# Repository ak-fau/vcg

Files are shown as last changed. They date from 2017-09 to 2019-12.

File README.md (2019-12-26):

# Versatile Clock Generator (VCG)

The VCG module is a stable and precise frequency source designed to be used
in experiments with time keeping (GPSDO), clock synchronization (PTPv2, IEEE-1588)
and Software Defined Radio (SDR).  Base frequency tuning, PLL configuration
and system monitoring (temperature and power consumption) are implemented
with I2C-bus connected devices.

The hardware is designed with free/open-source KiCAD EDA Software Suite.

_**Disclaimer**
The design and ideas are not very original ones, there are many similar devices
available in real products or on the Internet. The sole purpose of this
project is to build a convenient and universal module for the author's own
education and use and to release it explicitly as a Free Hardware Design._

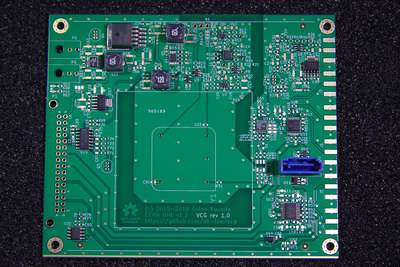
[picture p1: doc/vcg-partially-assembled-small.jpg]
Partially assembled VCG board


## Structure

The VCG board is build around oven controlled crystal oscillator (OCXO).

10 MHz output of the oscillator is buffered on the board with low
skew/low jitter clock driver IC and routed to receivers.
A programmable PLL synthesizer/multiplier/dividers synchronized to
the base frequency is provided on the board to generate output
frequencies up to 300 MHz.

Board temperature and OCXO power consumption are monitored with a
system controller device connected to an I2C bus. This I2C bus is also
used to access PLL control registers, DAC for oscillator tune voltage
and EEPROM (or FRAM) for calibration parameters and log data.  All
the control signals and output frequency are available on
a control board connector.  Future plans include design of an MCU and/or
FPGA based control boards tailored for different applications.
Base output frequency and programmable PLL outputs are routed
to the SMA connector (single ended LVCMOS signals) and SATA-type
connector (LVDS signals) for external use.

The module is powered from external stabilized +5V power supply,
all internal circuits run at +3.3V power obtained with two on-board
LDO regulators.

### Crystal Oscillator

Abracon AOCJY3-10.000MHz OCXO (0..50 oC, +/-5ppb) is used as a base
frequency source on the board.

For experiments with other (less accurate/less stable) crystals and to
test system monitoring circuits a separate small module is developed.
The module may be plugged into the main VCG board in place of AOCJY3
oscillator and provides 10 MHz output (10ppb..50ppm) and +3.3V power
load (up to five 10 Ohm resistors connected in parallel).  Design
files for the module are available under osc/ directory.

### PLL

Texas Instruments CDCE706

### Clock buffers

 - LV-CMOS
   Texas Instruments CDCLVC1104/06

 - LVDS
   Texas Instruments SN65LVDS1

### Oscillator tune voltage DAC

Linear Technology LTC2607-1

### System monitoring

Texas Instruments TMP512

### Calibration parameters and data log F-RAM

Cypress Semiconductors FM24CL64B

## References

### Power connector

### Control module connector

### Output connectors

### Components documentation

## License

The VCG is a Free Hardware project, it is released under
dual licenses:

 - CERN Open Hardware License (OHL) v1.2
 - Community Research and Academic Programming License (CRAPL)

All design documents (including textual description, diagrams,
schematic, PCB layout and manufacturing files) are released under CERN
OHL v1.2.  The design is done with KiCAD EDA Software Suite which is
available under GNU GPL v2.

The author will appreciate to be informed about any use of the project
documents under Section 4.2 of the CERN OHL v1.2, but does not require
so.

In addition to the CERN OHL v1.2 all the project materials are covered
by Community Research and Academic Programming License (CRAPL).

Associated software, firmware, bitware (programmable logic
configuration) required for the VCG use will be licensed separately
under free/open-source software license(s) decided upon at a respective
release time.

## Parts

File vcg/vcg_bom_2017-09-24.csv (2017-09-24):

Designator | Manufacturer Part Number | Quantity
C66,C95,C92,C91,C90,C89,C86,C85,C82,C81,C80,C79,C76,C75,C70,C69,C45,C44,C41,C40,C39,C37,C36,C35,C34,C33,C31,C30,C28,C26,C25,C24,C23,C22,C18,C14,C7,C4,C3 | C0603C104K8RACTU | 39
L13,L14,L12 | 7447779112 | 3
U21,U17 | TPS73633DCQR | 2
R79,R38,R35,R34,R8,R7,R6,R5,R4 | ERJ-3GEY0R00V | 9
C96,C93,C84,C83,C78,C77,C72,C71,C68,C67,C65,C64,C63,C38,C17 | C1210C106K8RACTU | 15
C94,C74,C73,C62,C61,C58,C57,C56,C55,C54,C52,C51,C50,C49,C20,C11 | C0603C103K8RACTU | 16
J2 | 0678005003 | 1
U20 | FM24CL64B-G | 1
U19 | TMP512AID | 1
U18 | TPS78633KTT | 1
U15,U14,U11,U10 | SN65LVDS1DBV | 4
U13 | CDCE706PW | 1
U12 | CDCLVC1106PW | 1
U9 | LTC6957IMS-4#PBF | 1
U8 | LT6210CS6#PBF | 1
U7,U6,U4,U3 | LTC2050CS5#PBF | 4
U5 | LTC2607CDE-1#PBF | 1
U2 | ADR280ARTZ | 1
U1 | SN74LVC2G66DCTR | 1
T1 | TC1-1TX+ | 1
R78,R75,R51,R50,R44,R25,R24,R18,R3 | ERJ-3EKF1002V | 9
R77,R76,R11,R10 | ERJ-3EKF4752V | 4
R74,R73,R72,R71,R42,R41,R26 | ERJ-3EKF49R9V | 7
R70,R69,R63,R62,R61,R57,R56,R55,R48 | ERJ-3EKF22R0V | 9
R68,R67,R49,R22,R19,R2,R1 | ERJ-3EKF1001V | 7
R66 | ERJ-8CWFR025V | 1
R65,R64,R37 | ERJ-3EKF2490V | 3
R60,R59,R58,R54,R53,R52,R17 | ERJ-3EKF10R0V | 7
R47 | ERJ-3EKF15R0V | 1
R45 | ERJ-3EKF1301V | 1
R43 | ERJ-3EKF1540V | 1
R40,R36 | ERJ-3EKF2001V | 2
R33,R32,R30 | ERJ-3EKF1000V | 3
R31 | ERJ-3EKF75R0V | 1
R29 | ERJ-3EKF4751V | 1
R28,R21,R13 | ERJ-3EKF2002V | 3
R27 | ERJ-3EKF1302V | 1
R20 | HVCB0603FDD20M0 | 1
R16 | ERJ-3EKF2102V | 1
R15,R12,R9 | ERJ-3EKF2802V | 3
R14 | ERJ-3EKF8252V | 1
L11,L10,L9,L8,L7,L6,L2,L1 | LQM18PN4R7MFRL | 8
L5,L3 | LQW21HN2R2J00L | 2
L4 | LQW18ANR13G00D | 1
DS2,DS1 | LTST-C194KSKT | 2
C88,C87,C32,C27 | ECH-U1H101GX5 | 4
C60,C59,C53,C48,C47,C46,C19,C15,C12,C9,C8,C5 | C0805C105K4RACTU | 12
C43 | C0603C332G3GEC7867 | 1
C42 | C1206C225J3RACTU | 1
C29 | ECH-U1H221GX5 | 1
C21,C16,C13,C10,C6 | C0603C102K3RACTU | 5
U16 | LTC4415EMSE#PBF | 1

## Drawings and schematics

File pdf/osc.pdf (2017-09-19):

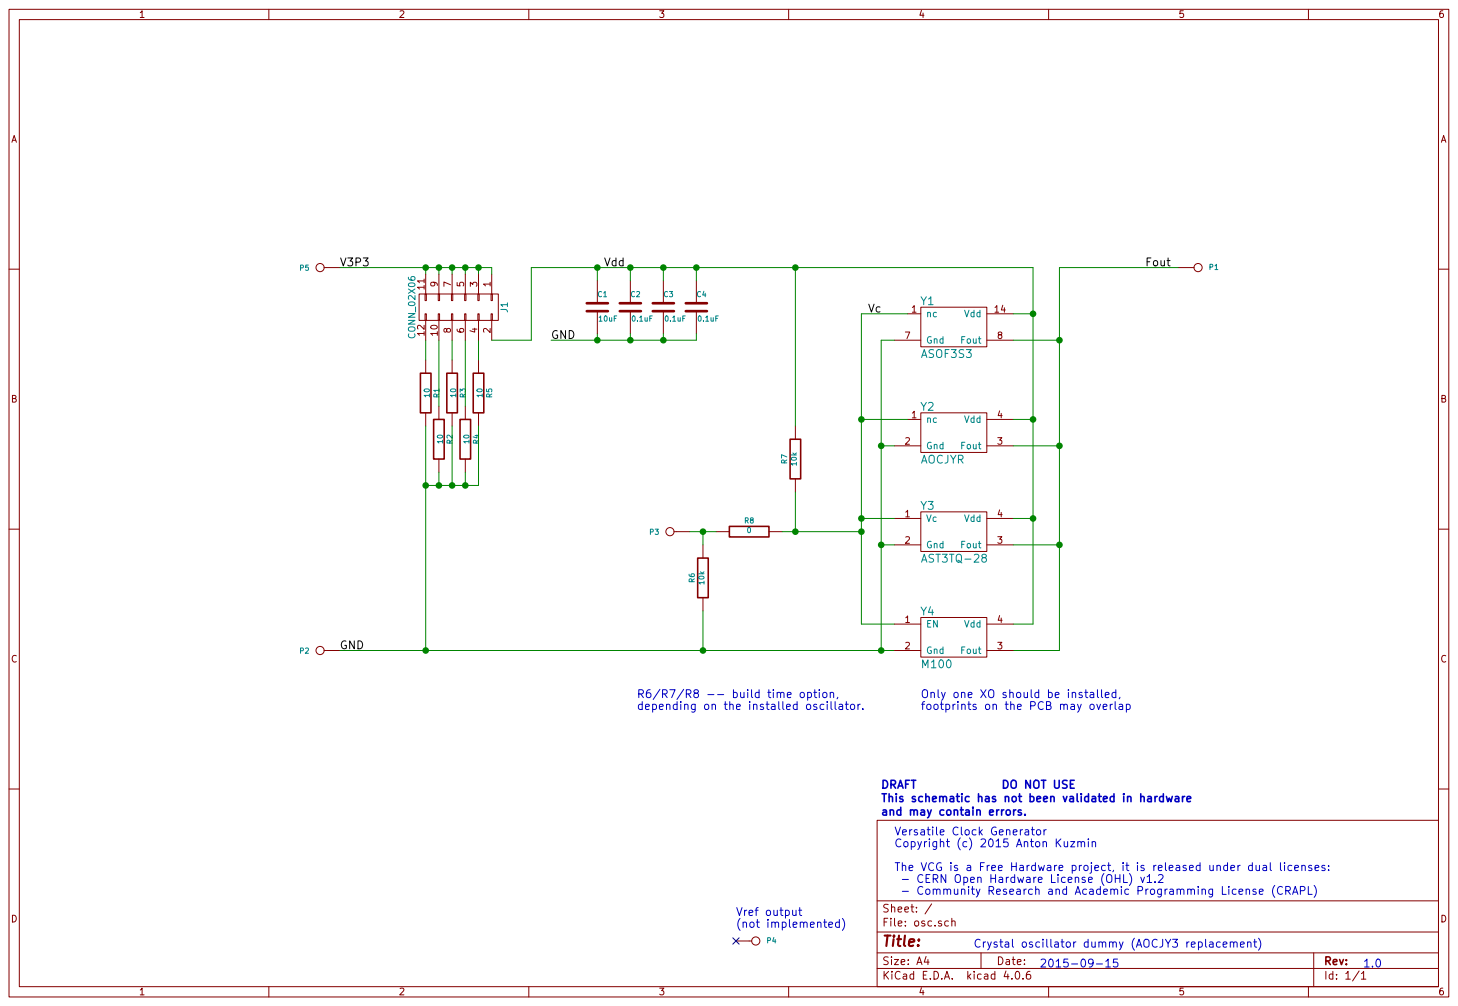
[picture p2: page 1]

Only one XO should be installed,
footprints on the PCB may overlap

This schematic has not been validated in hardware

Versatile Clock Generator
Copyright (c) 2015 Anton Kuzmin
The VCG is a Free Hardware project, it is released under dual licenses:
- CERN Open Hardware License (OHL) v1.2
- Community Research and Academic Programming License (CRAPL)
Id: 1/1 Title: File: osc.sch Sheet: /

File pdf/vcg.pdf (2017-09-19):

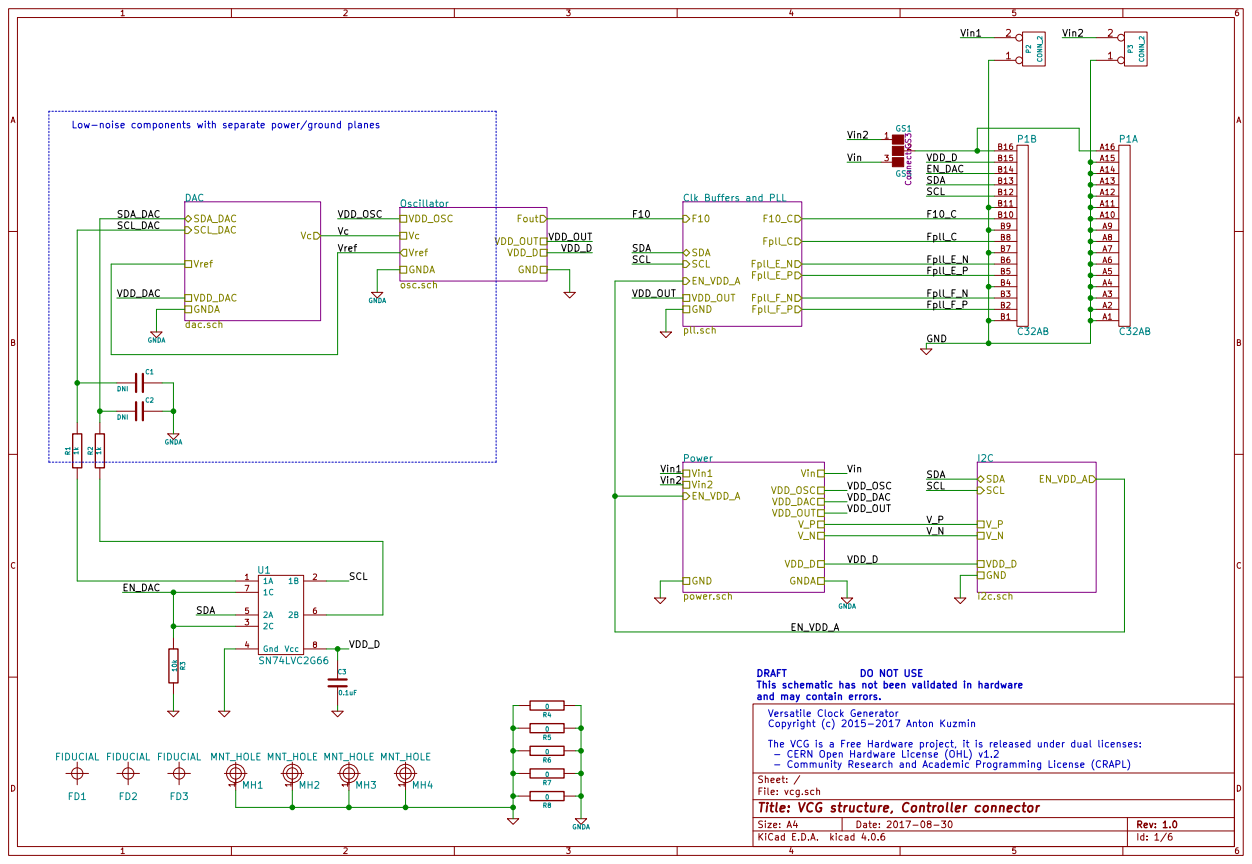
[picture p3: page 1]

Low-noise components with separate power/ground planes

VDD_D
EN_DAC

Clk Buffers and PLL
pll.sch F10 SDA
VDD_OUT Power power.sch
GND

F10 VDD_DAC

Fpll_E_P

Fpll_F_P

This schematic has not been validated in hardware
and may contain errors.
File: vcg.sch Sheet: / Versatile Clock Generator
Copyright (c) 2015-2017 Anton Kuzmin
The VCG is a Free Hardware project, it is released under dual licenses:
- CERN Open Hardware License (OHL) v1.2
- Community Research and Academic Programming License (CRAPL)

Id: 1/6 Title: VCG structure, Controller connector

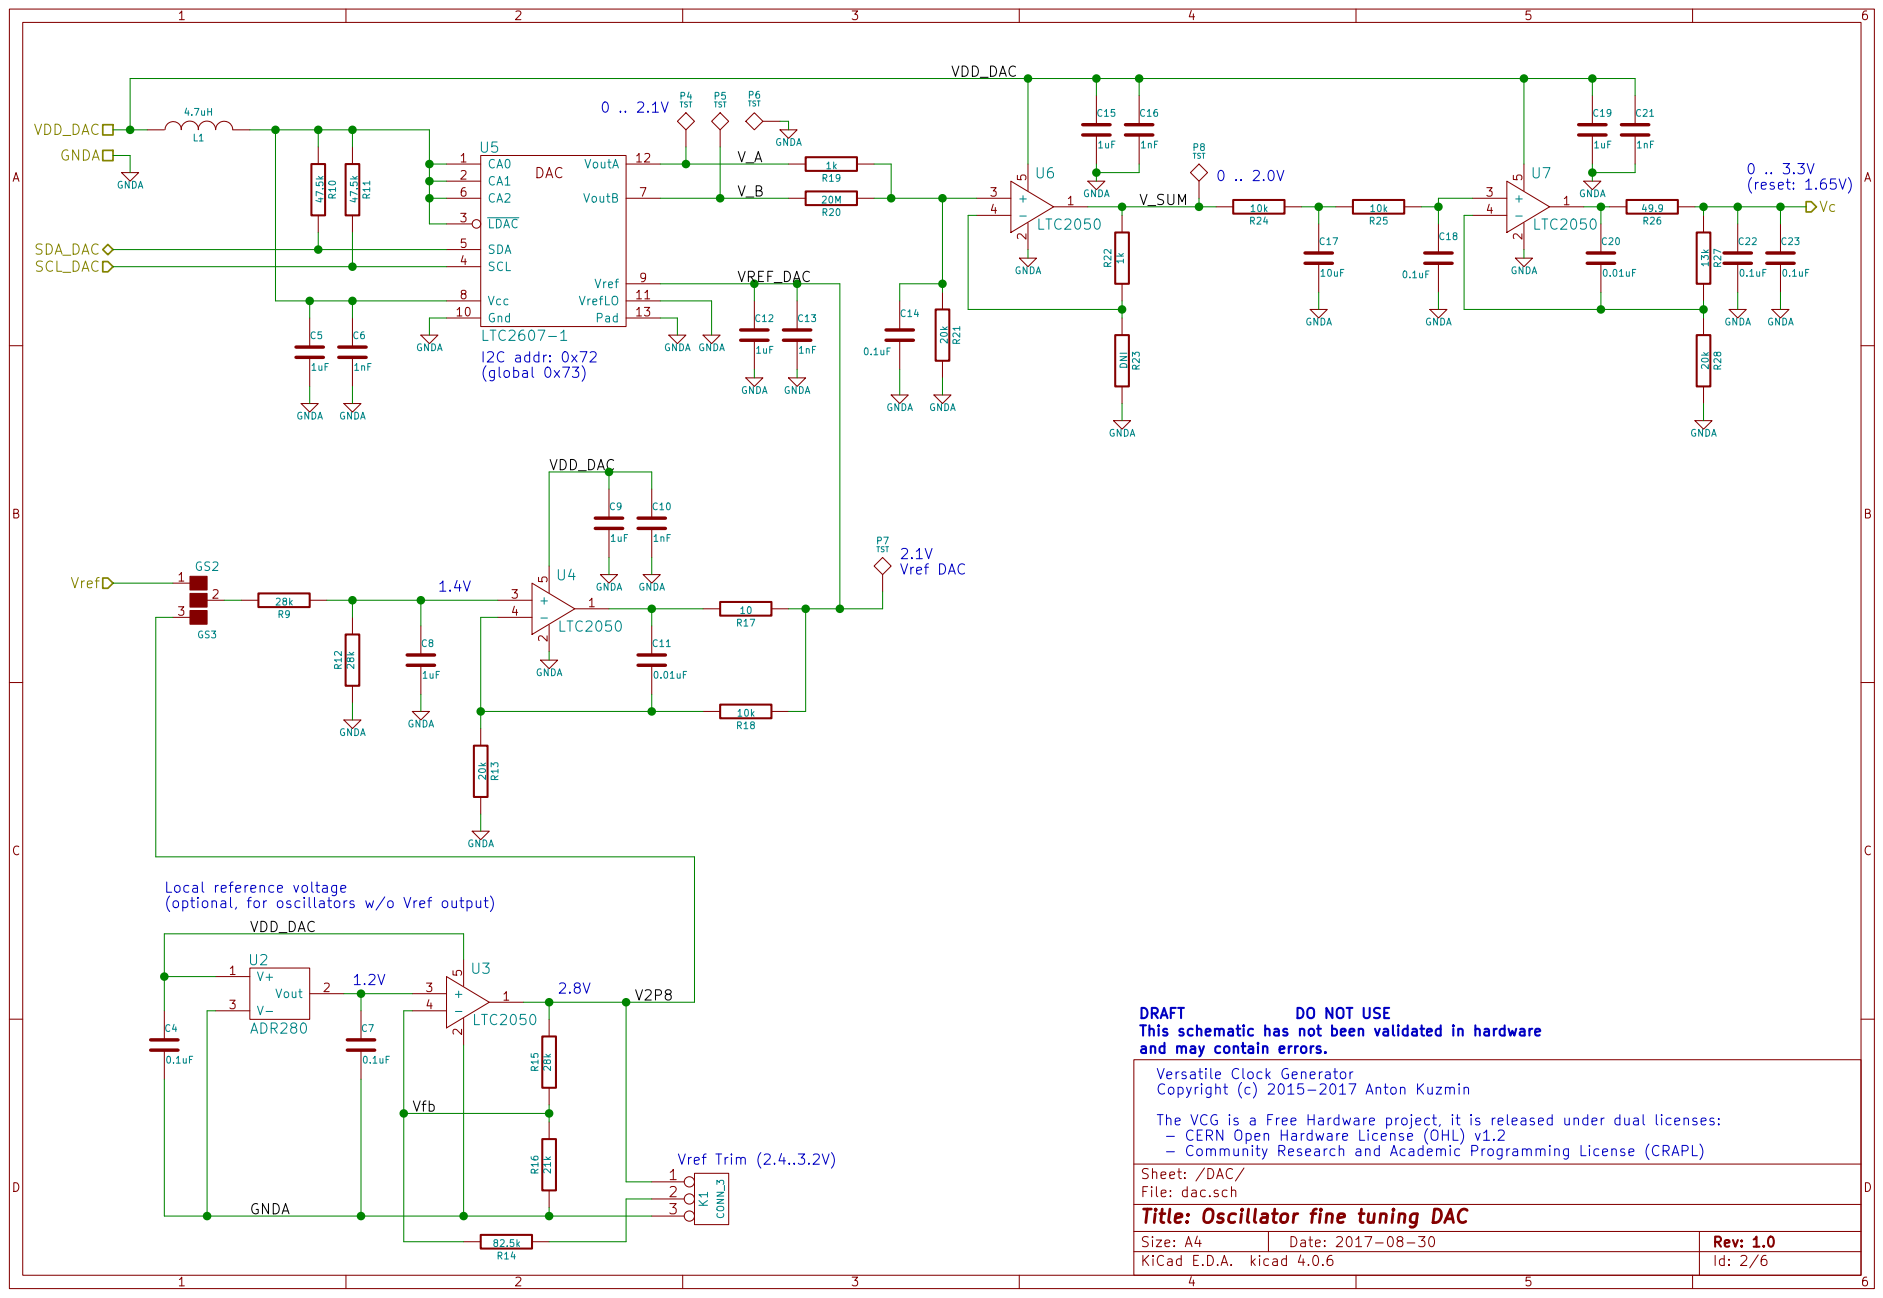
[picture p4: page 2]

Local reference voltage
(optional, for oscillators w/o Vref output)

This schematic has not been validated in hardware

File: dac.sch Sheet: /DAC/ Versatile Clock Generator
Copyright (c) 2015-2017 Anton Kuzmin
The VCG is a Free Hardware project, it is released under dual licenses:
- CERN Open Hardware License (OHL) v1.2

Id: 2/6 Title: Oscillator fine tuning DAC

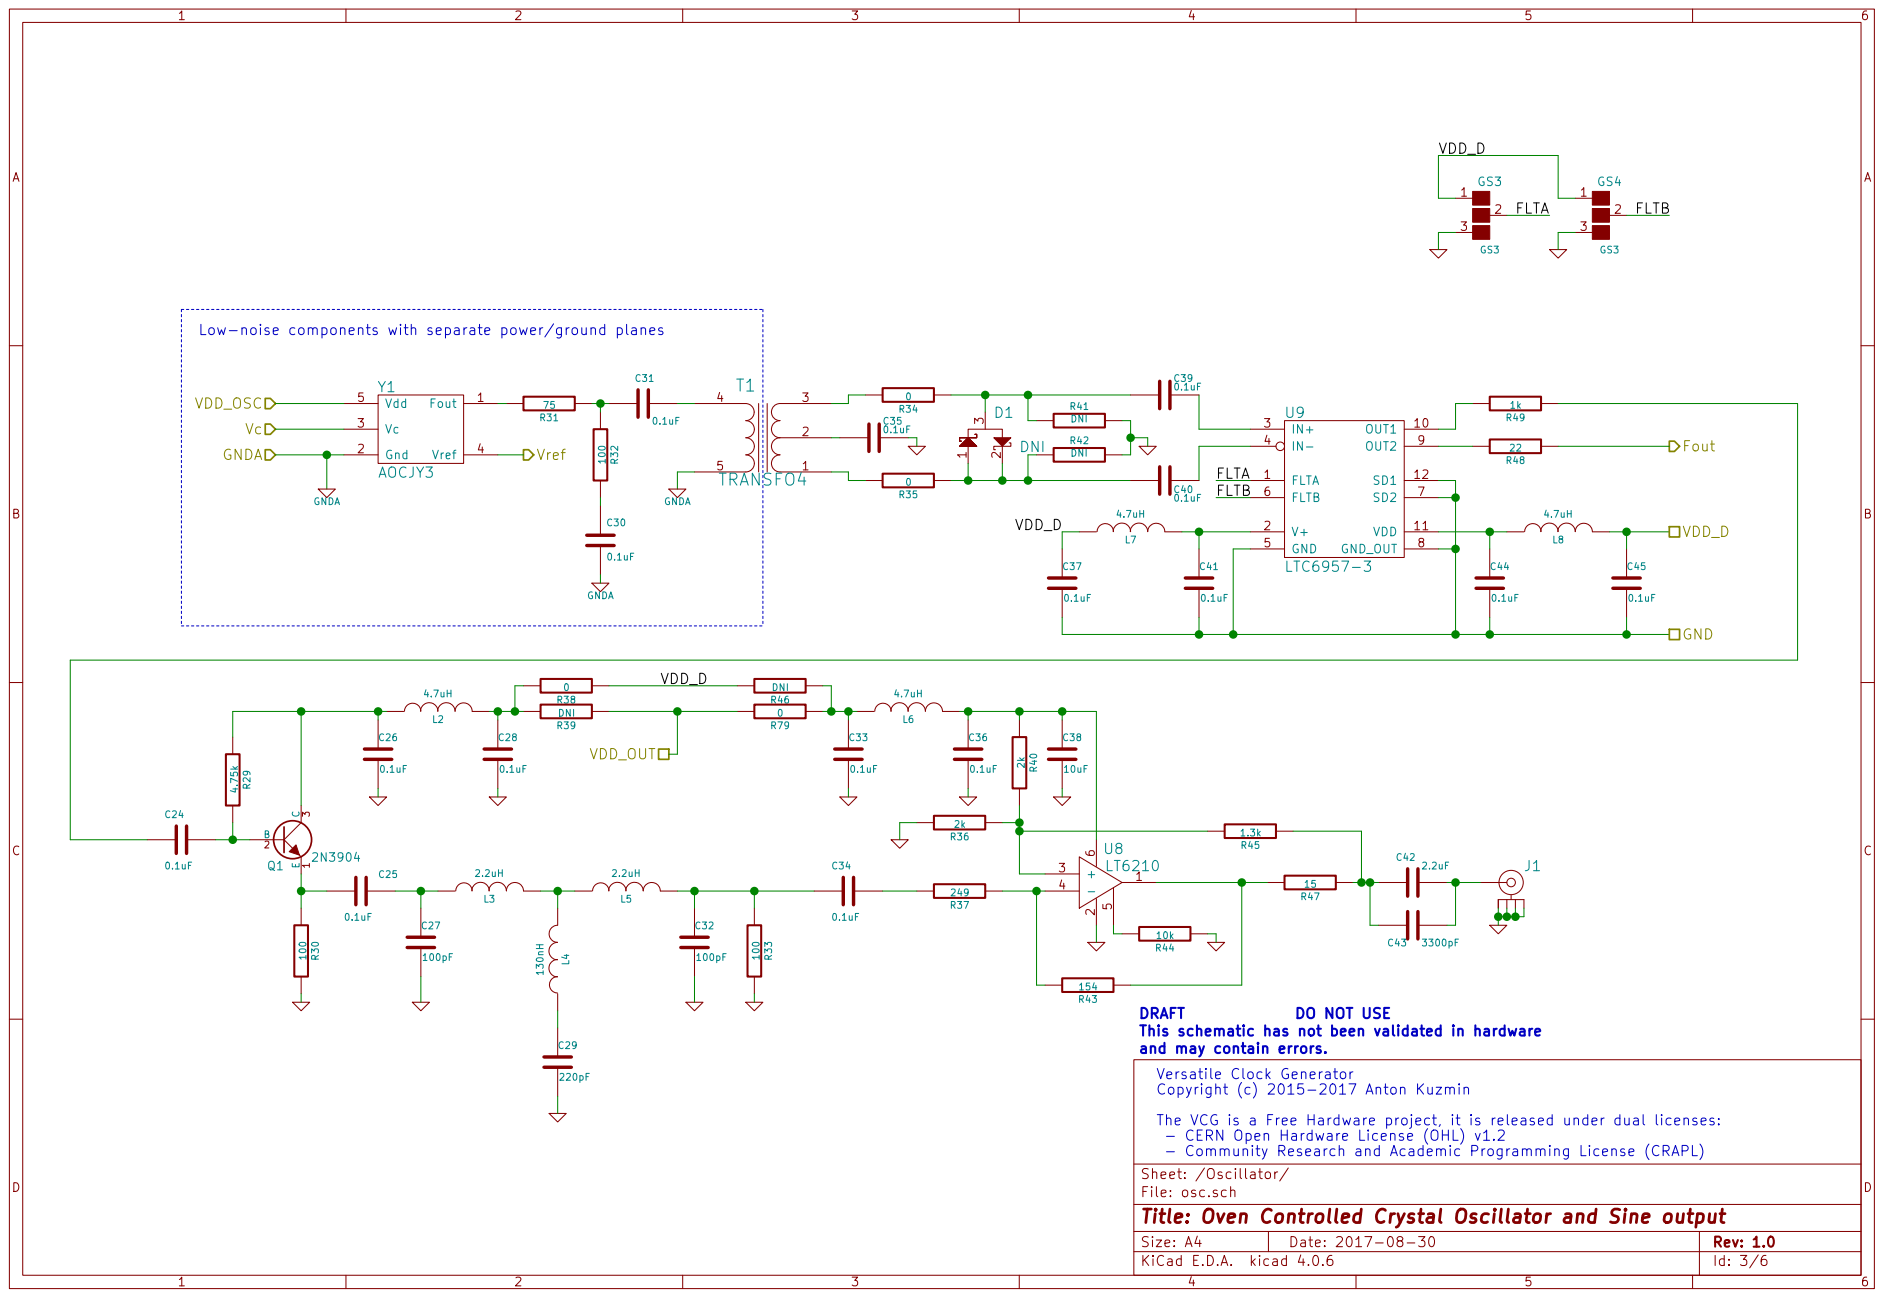
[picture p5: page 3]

This schematic has not been validated in hardware
and may contain errors.
Versatile Clock Generator
Copyright (c) 2015-2017 Anton Kuzmin
The VCG is a Free Hardware project, it is released under dual licenses:
- CERN Open Hardware License (OHL) v1.2
- Community Research and Academic Programming License (CRAPL)

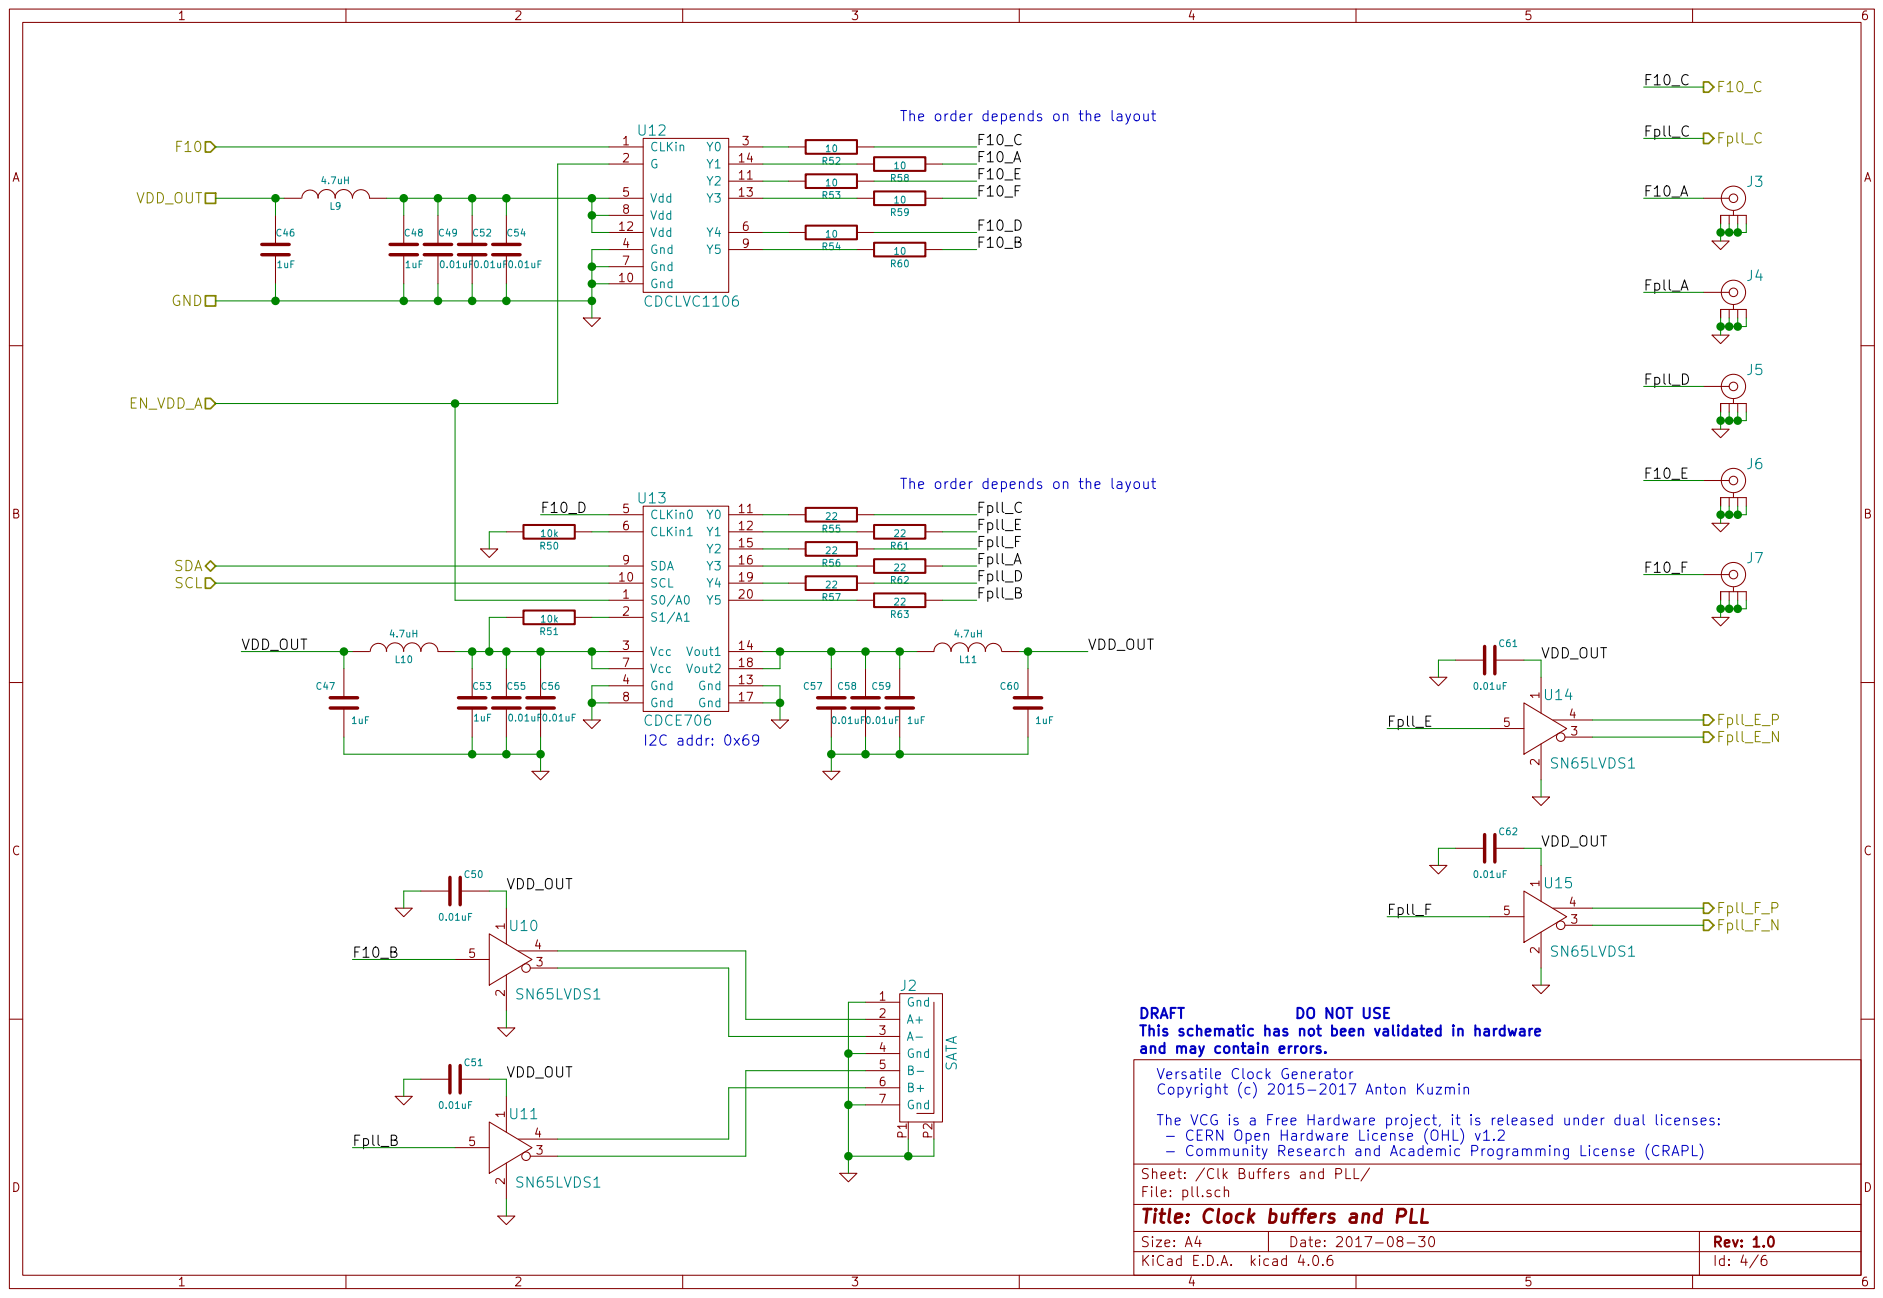
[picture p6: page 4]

The order depends on the layout

22The order depends on the layout R57

and may contain errors. C60

This schematic has not been validated in hardware

File: pll.sch Sheet: /Clk Buffers and PLL/ Versatile Clock Generator
Copyright (c) 2015-2017 Anton Kuzmin
The VCG is a Free Hardware project, it is released under dual licenses:
- CERN Open Hardware License (OHL) v1.2
- Community Research and Academic Programming License (CRAPL)

Id: 4/6 Title: Clock buffers and PLL

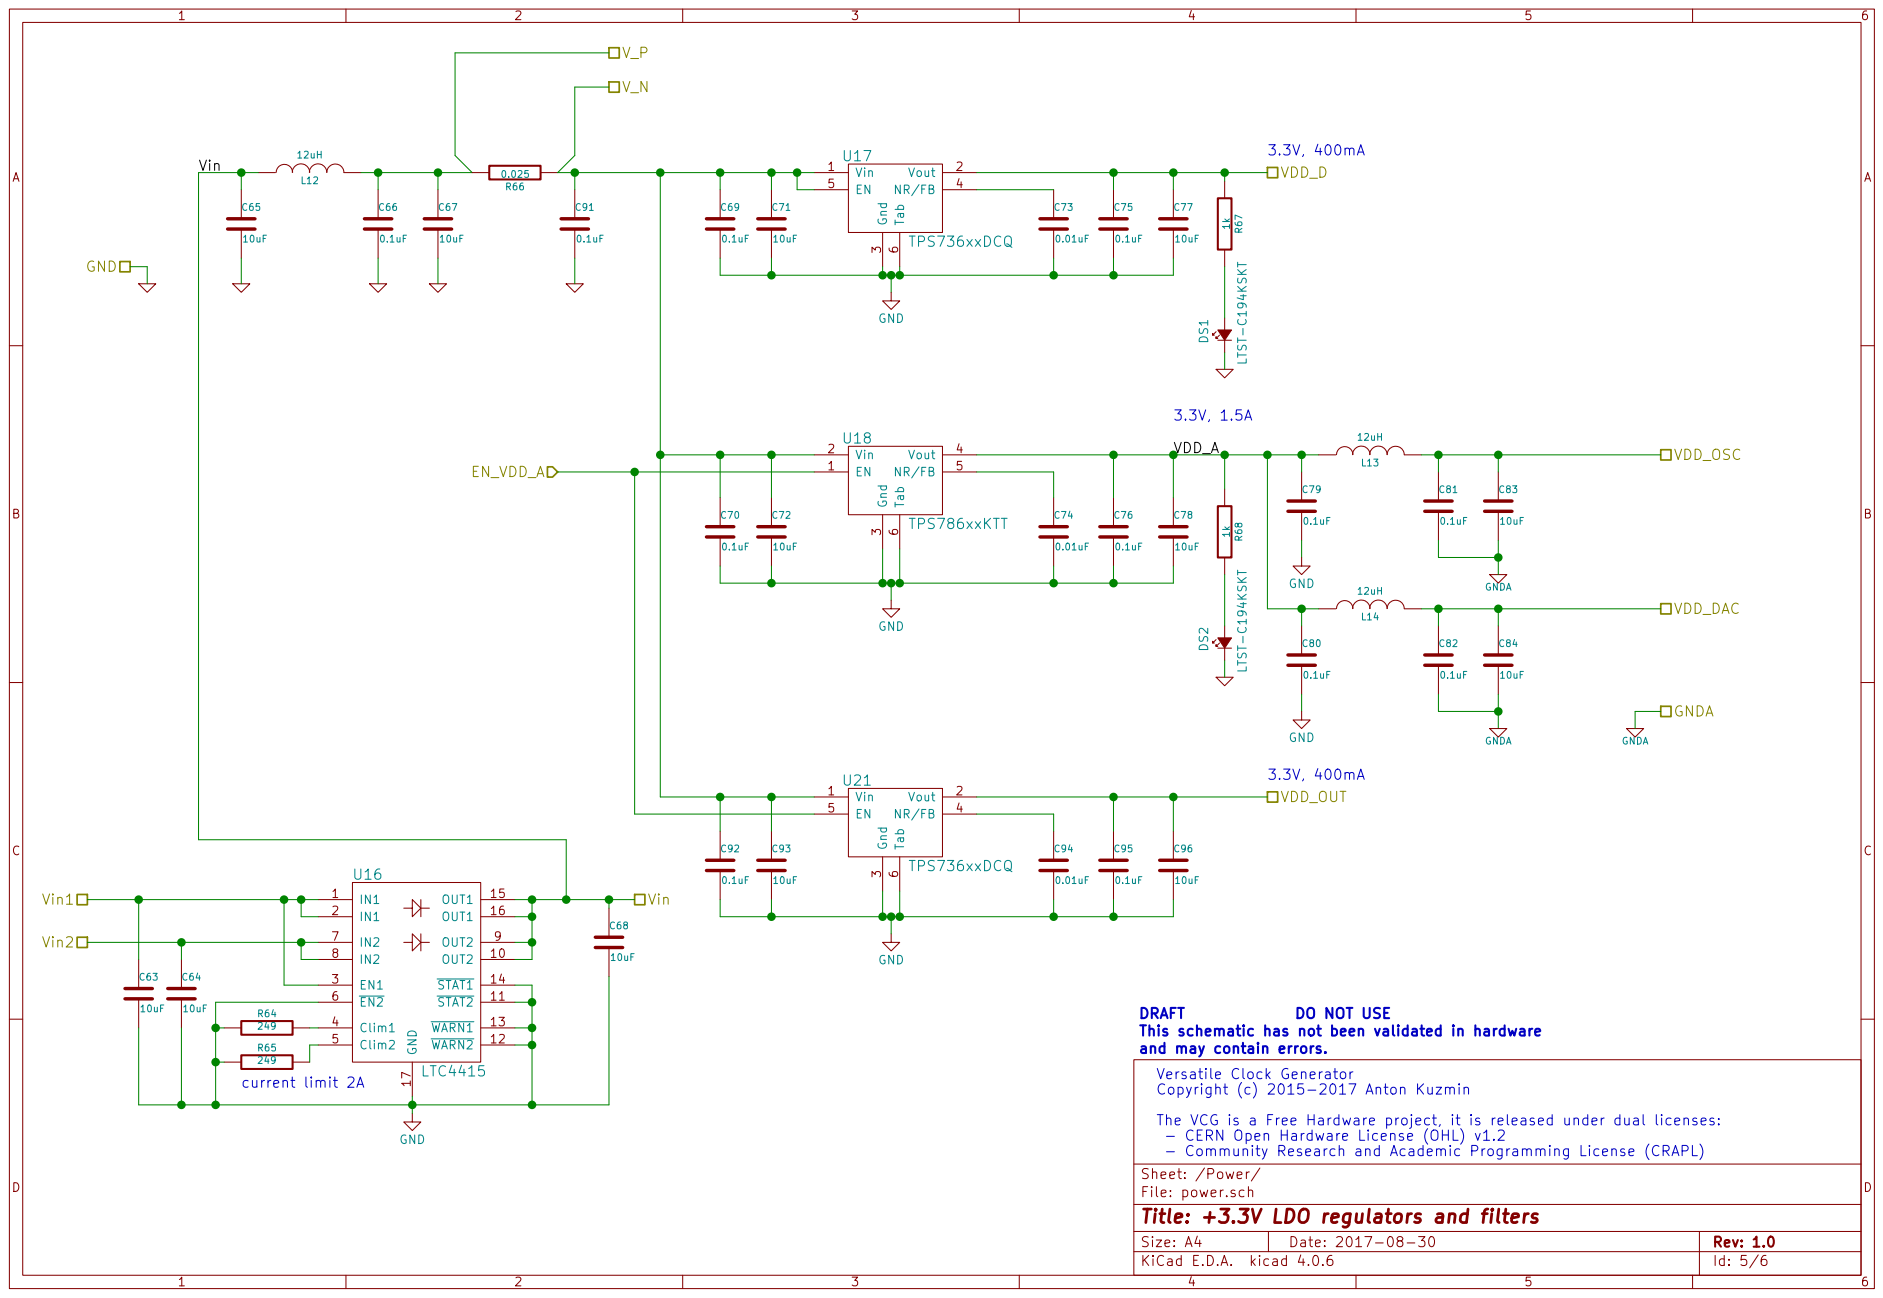
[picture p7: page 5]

and may contain errors. R67 1k R68 1k

3 NR/FB 4 EN 5 Tab

3 Vout 4 NR/FB 5 Tab

This schematic has not been validated in hardware

File: power.sch Sheet: /Power/ Versatile Clock Generator
Copyright (c) 2015-2017 Anton Kuzmin
The VCG is a Free Hardware project, it is released under dual licenses:
- CERN Open Hardware License (OHL) v1.2
- Community Research and Academic Programming License (CRAPL)

Id: 5/6 Title: +3.3V LDO regulators and filters

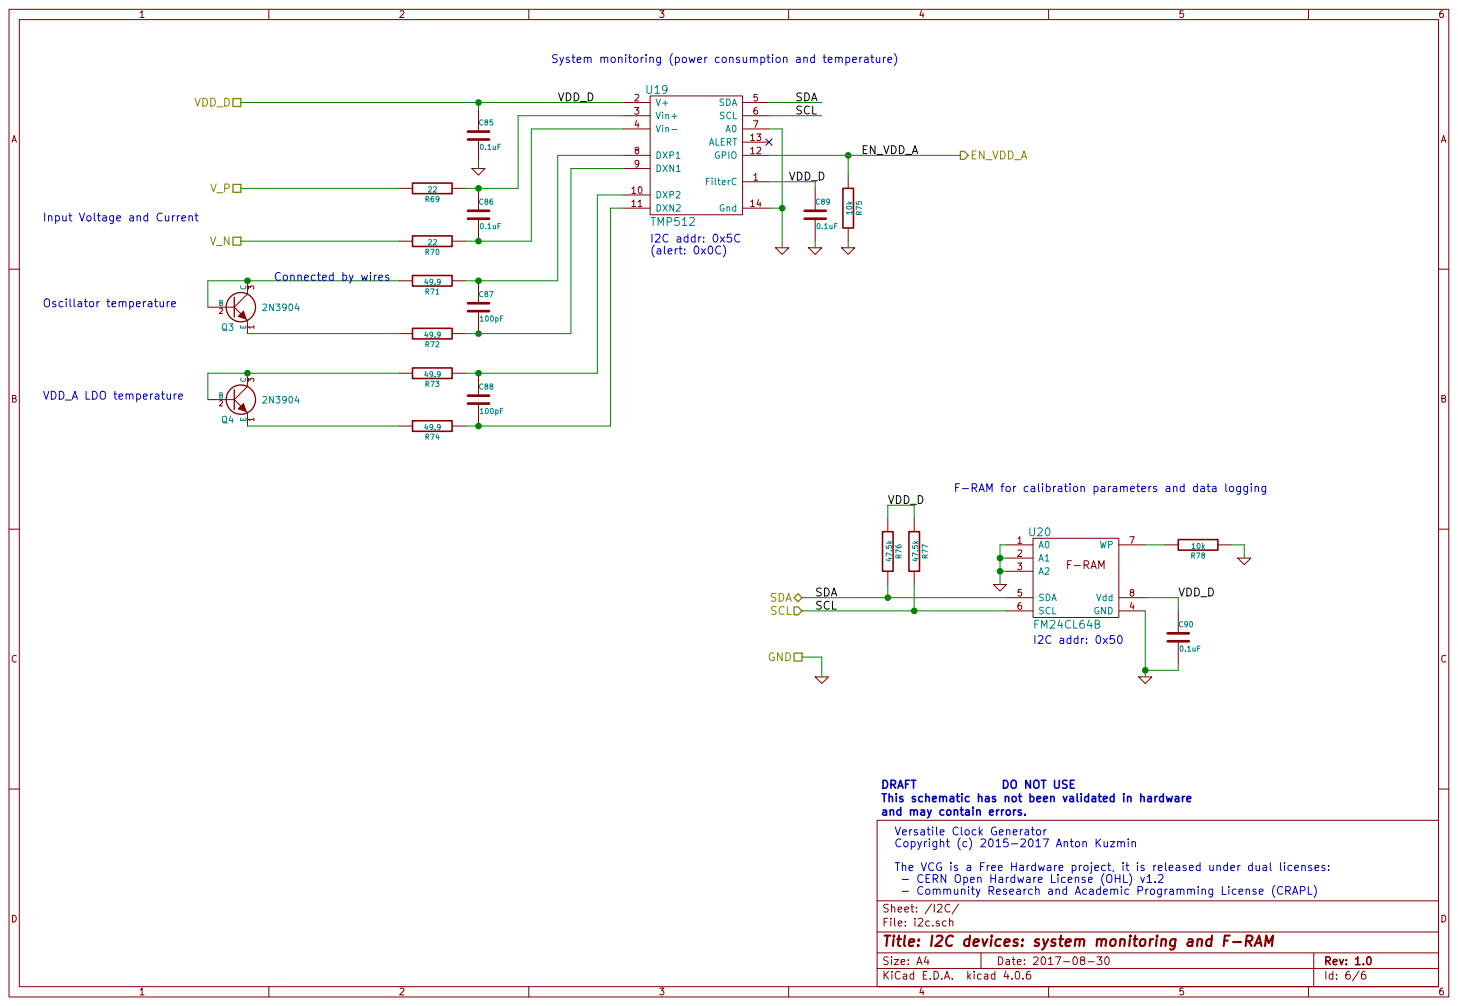
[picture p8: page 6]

Input Voltage and Current

F-RAM for calibration parameters and data logging

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

Id: 6/6 Title: I2C devices: system monitoring and F-RAM

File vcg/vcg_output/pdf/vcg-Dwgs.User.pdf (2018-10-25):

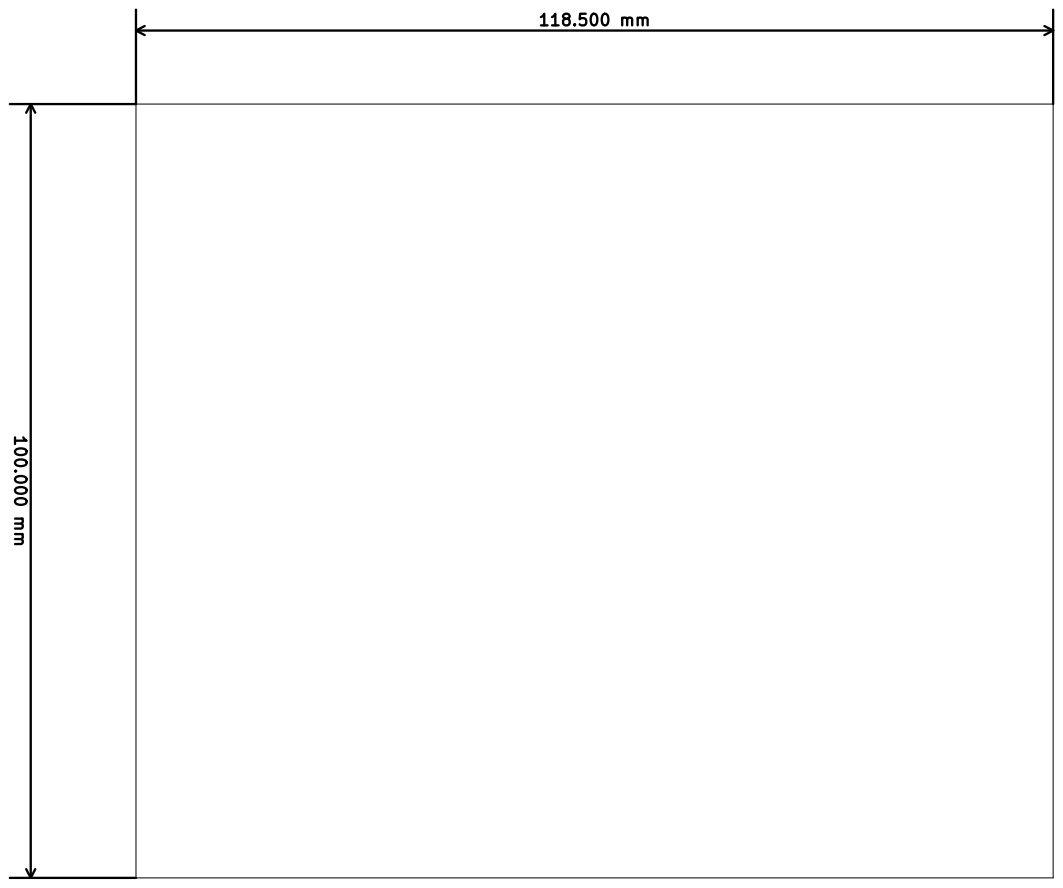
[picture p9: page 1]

File: vcg.kicad_pcb Sheet: 100.000 mm

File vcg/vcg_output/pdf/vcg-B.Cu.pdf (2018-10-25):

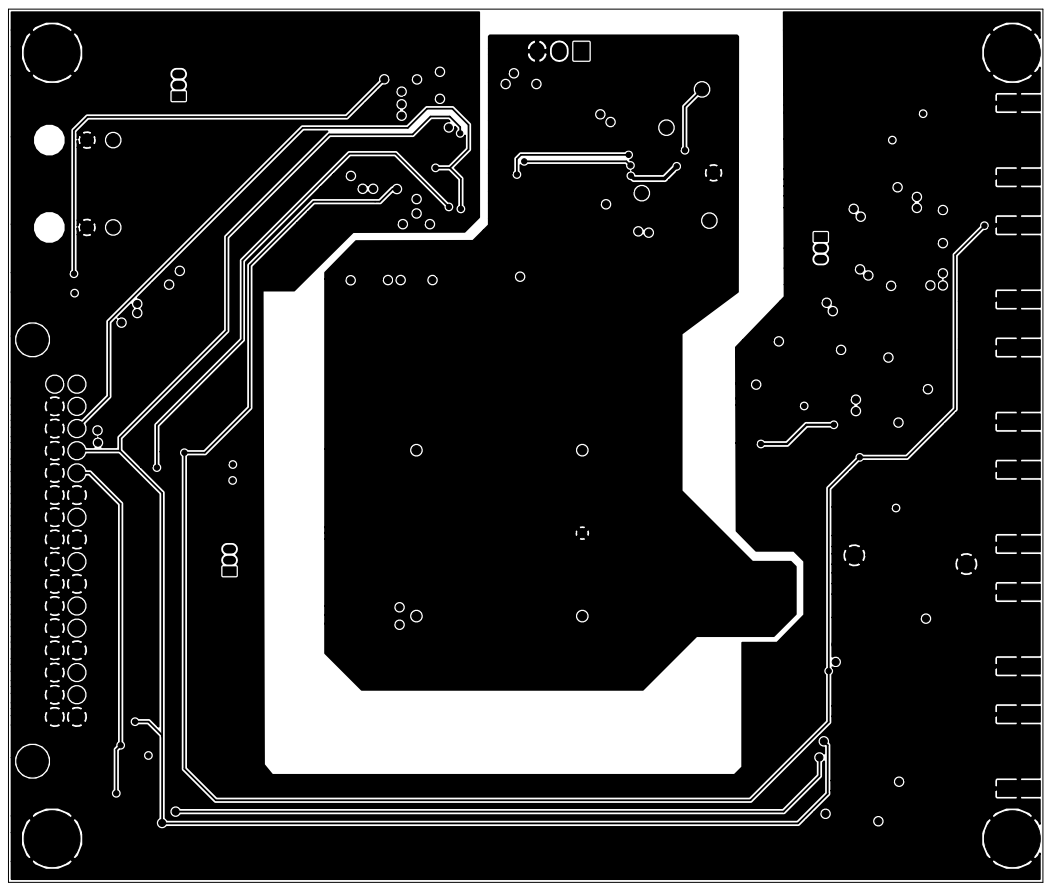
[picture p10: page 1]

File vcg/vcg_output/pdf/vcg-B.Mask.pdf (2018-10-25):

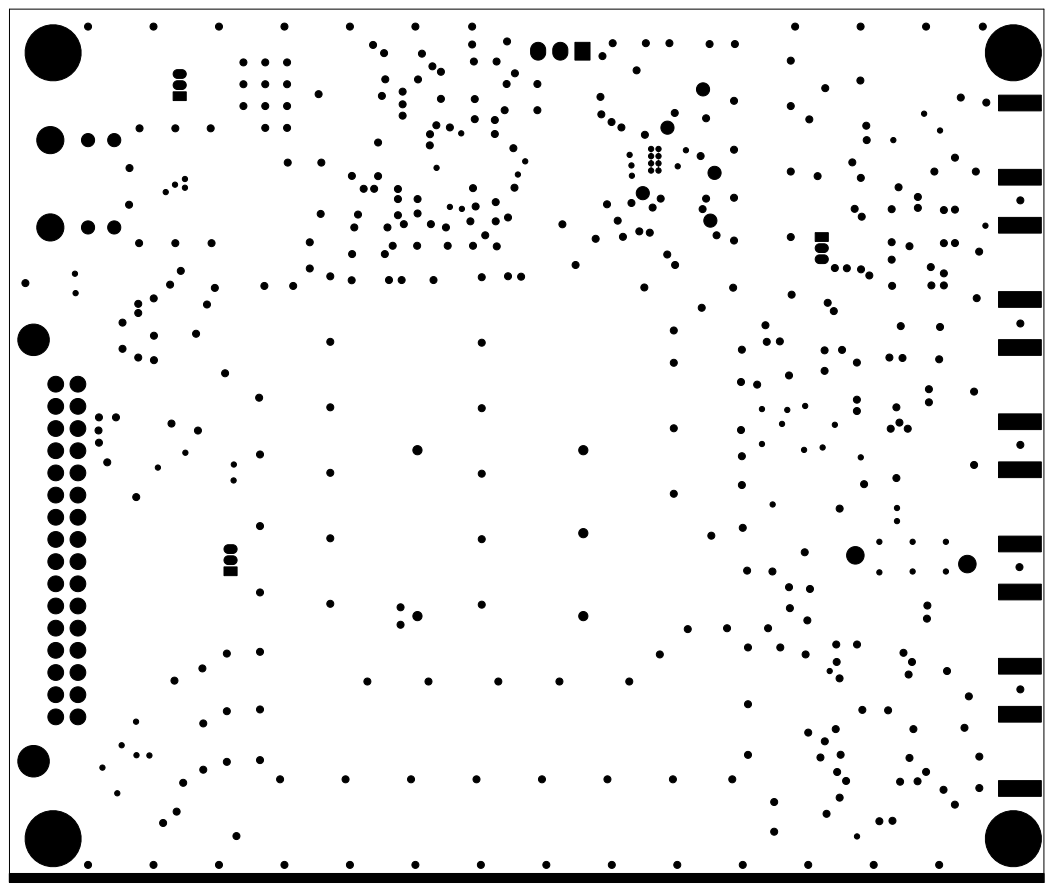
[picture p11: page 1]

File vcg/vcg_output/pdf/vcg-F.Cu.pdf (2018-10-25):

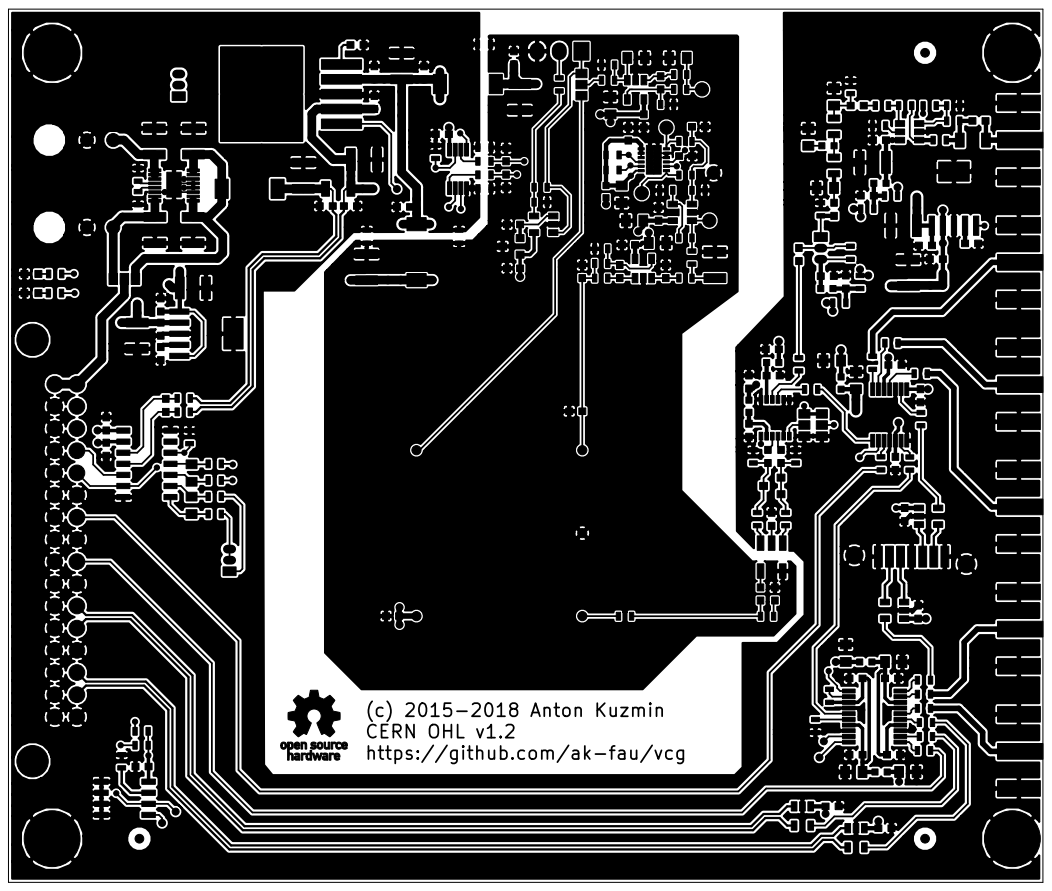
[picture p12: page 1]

(c) 2015-2018 Anton Kuzmin CERN OHL v1.2 https://github.com/ak-fau/vcg

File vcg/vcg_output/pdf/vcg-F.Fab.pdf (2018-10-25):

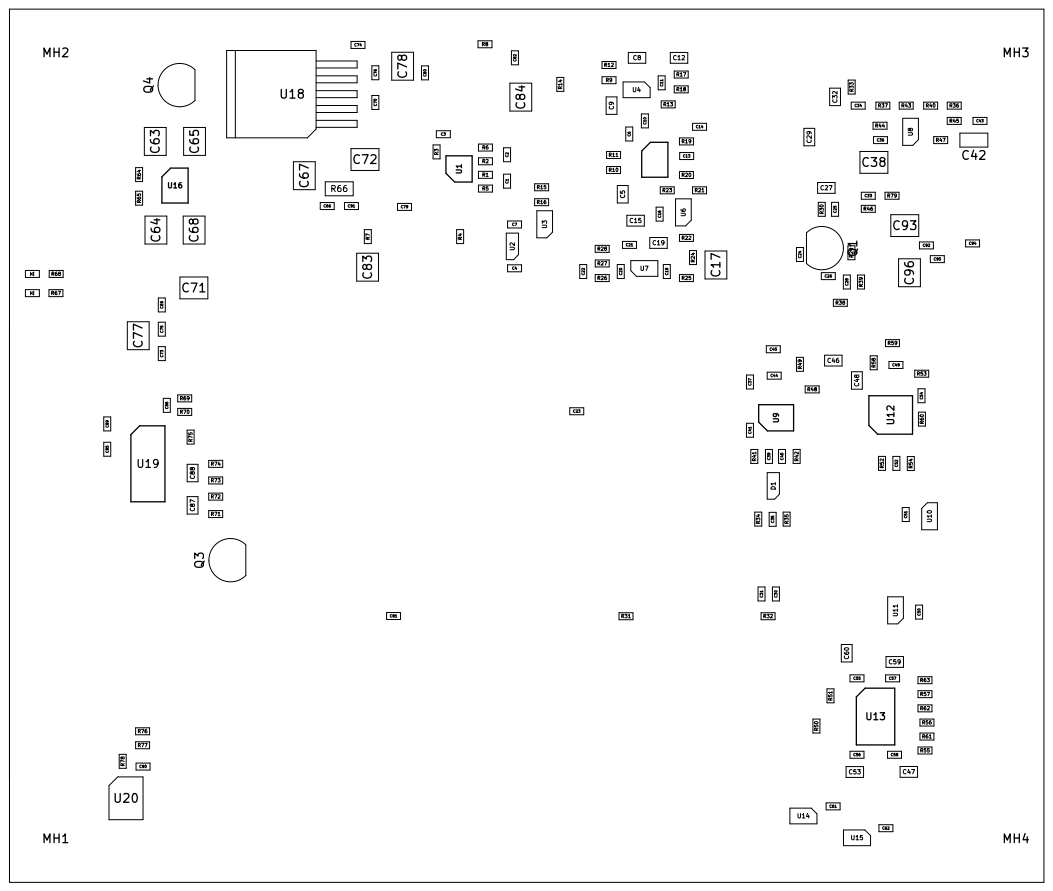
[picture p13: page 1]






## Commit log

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2015-09-21 Oscillator module project and schematic are created.
    [osc.sch]
2015-09-21 VCG project and schematic hierarchy are created.
    [dac.sch, i2c.sch, pll.sch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]
2015-09-21 Correct DIN 41612 connector type
    [vcg.sch]
2015-09-22 Power and I2C schematics are created, initial content for DAC and PLL.
    [dac.sch, i2c.sch, pll.sch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]
2015-09-22 DAC schematic is created.
    [dac.sch]
2015-09-22 Reference voltage source is removed (moved to the main board DAC sheet)
    [osc.sch]
2015-09-23 Add resistor to Vref trimming circuitry and cap to the DAC summing point, calculate resistors values.
    [dac.sch]
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2015-09-23 PLL and clock buffers sheet is created.
    [pll.sch]
2015-09-23 Draft/Do not use text is added to all schematic sheets.
    [dac.sch, i2c.sch, pll.sch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]
2015-09-23 Draft/Do not use text is added to the oscillator schematic.
    [osc.sch]
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2015-10-14 Move OCXO to a separate schematic sheet
    [dac.sch, i2c.sch, osc.sch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]
2015-10-14 Transfer OCXO output from analog to digital domain via transformer and low phase noise clock buffer.
    [osc.sch, vcg.sch]
2015-10-14 Changes based on initial discussion with colleagues
    [dac.sch, osc.sch, pll.sch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]
2015-10-26 Refactor circuitry around transformer -- more TODO after prototyping.
    [osc.sch]
2015-10-26 Add i2c device addresses
    [i2c.sch, pll.sch]
2015-10-26 Change DC operational point to keep Vcm < 2.3V for all LTCs, based on LTspice simulation results.
    [dac.sch]
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2015-10-27 Change schematic sheet order.
    [dac.sch, i2c.sch, osc.sch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]
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2015-11-02 Fiducal marks and mounting holes are added.
    [vcg.sch]
2015-11-04 Add a feedback cap to stabilize op amp working on a capacitive load.
    [dac.sch]
2015-11-09 Add a [one more] feedback cap to stabilize op amp working on a capacitive load.
    [dac.sch]
2015-11-09 Add load resistor on the control voltage input (Vc)
    [osc.sch]
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2016-03-10 Update schematic to a newer KiCAD version (create rescue library)
    [osc.sch]
2016-03-10 Change pull-up/-down and zero-Ohm jumper to accomodate oscillators with different signals on pin 1
    [osc.sch]
2016-04-03 Add footprint information for passive components.
    [osc.sch]
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2016-04-03 Replace Y4 to M100: Con-Win LVCMOS in 2.5x3.2 mm package.
    [osc.sch]
2016-04-05 Add Y4 footprint: SMT XO 5.0 x 3.2 mm
    [osc.sch]
2016-04-05 PCB files and initial layout (except XOs) are added.
    [osc.kicad_pcb]
2016-04-05 Add Y3 footprint: SMT XO 7.0 x 5.0 mm
    [osc.kicad_pcb, osc.sch]
2016-04-16 All footprints are created and added to the schematic and the board.
    [osc.kicad_pcb, osc.sch]
2016-04-16 Add an extra .1uF cap (build-time option, depends on the Osc assembled)
    [osc.kicad_pcb, osc.sch]
2016-04-16 Yet another .1uF cap.
    [osc.sch]
2016-04-16 Initial routing of all the signals (except ground connections)
    [osc.kicad_pcb]
2016-04-17 Ground connections and zone fill
    [osc.kicad_pcb]
2016-05-06 Remove ref.designators, add net labels for external signals.
    [osc.kicad_pcb]
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2016-05-18 Sine output: emitter follower, LPF, line driver (current-feedback amp.)
    [osc.sch]
2016-05-22 Improve DC operation point, reduce power consumption of the emitter follower.
    [osc.sch]
2016-05-25 An extra cap to filter output op.amp power
    [osc.sch]
2016-06-27 A few components to tune/match osc-transformer-comparator chain (CYA). Re-annotate all components.
    [dac.sch, i2c.sch, osc.sch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]
2016-06-27 Fix connectivity problems
    [dac.sch, vcg.sch]
2016-06-30 PCB file is created
    [vcg.kicad_pcb]
2016-07-04 Add footprint information and footprints.
    [dac.sch, i2c.sch, osc.sch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]
2016-07-04 P1, P2, P3, J2 connectors' footprints and connection adjustment
    [pll.sch, vcg.sch]
2016-07-04 Sync schematic and pcb files, clean-up errors
    [osc.sch, pll.sch, vcg.kicad_pcb]
2016-07-18 Fix two broken connections.
    [dac.sch]
2016-07-18 Re-connect transformer to facilitate straight connections in layout.
    [osc.sch]
2016-07-18 Placement: group components, work in progress.
    [vcg.kicad_pcb]
2016-11-13 Preliminary placement and related changes to the schematic.
    [dac.sch, i2c.sch, osc.sch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]
2017-03-03 Experiments with smaller pcb: 120 x 100
    [vcg.kicad_pcb]
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2017-03-27 Filtes caps before inductors should be connected to "digital" Ground.
    [power.sch]
2017-03-29 LDOs and digital components are placed, TO-DO: analog reference and control voltage, PLL and output stages.
    [vcg.kicad_pcb]
2017-04-17 Preliminary placement on the 120x100 (small) PCB variant.
    [vcg.kicad_pcb]
2017-05-25 Separate power (optional?) for output drivers.
    [dac.sch, i2c.sch, osc.sch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]
2017-06-05 All footprints are updated to the most recent library version.
    [vcg.kicad_pcb]
2017-06-09 Rename V_M net to V_N to route current sense signals as a diff. pair
    [i2c.sch, power.sch, vcg.sch]
2017-06-10 Layout mostly done, split planes and ground poligons are created.
    [vcg.kicad_pcb]
2017-06-13 Only 5 un-connected nets have left... polygones are mostly done/cleaned-up
    [vcg.kicad_pcb]
2017-06-13 All nets connected. TO-DO: DRC, clean-up, silkscreen
    [vcg.kicad_pcb]
2017-06-13 Adjust diff.pair width/gap for manufacturability
    [vcg.kicad_pcb]
2017-08-26 Refactor oscillator board before releasing to manufacturing: trace width, combine headers to a single part, etc.
    [osc.kicad_pcb, osc.sch]
2017-08-26 Manufacturing files for the oscillator board.
    [osc-B.Cu.gbl, osc-B.Mask.gbs, osc-Edge.Cuts.gm1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]
2017-08-30 Silkscreen clean-up, copyright/lincese/revision notes
    [vcg.kicad_pcb]
2017-08-30 Update Title blocks: date/revision/page title
    [dac.sch, i2c.sch, osc.sch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]
2017-08-30 Clean-up resistor's values: K -> k
    [osc.sch]
2017-09-01 Prepare to generate manufacturing files.
    [vcg.kicad_pcb]
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2017-09-24 Final touches: stitching vias, DRC, cleanup
    [vcg.kicad_pcb]
2017-09-24 Open soldermask on the bottom pads
    [vcg.kicad_pcb]
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2018-10-22 Add open copper bar (ground) along the bottom of the PCB, update copyright year
    [vcg.kicad_pcb]
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2018-10-25 Update TO-92 footprint to address PCB house warnings, re-generate manufacturing files.
    [vcg-B.Cu.gbr, vcg-B.Mask.gbr, vcg-Edge.Cuts.gbr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]
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
